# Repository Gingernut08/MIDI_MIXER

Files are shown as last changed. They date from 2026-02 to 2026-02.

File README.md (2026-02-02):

This project lets you use a physical 10-channel MIDI mixer to control the volume of individual apps on Windows. Each fader maps to a specific application, so you can change levels in real time without alt-tabbing or digging through volume sliders.
I built this because I wanted actual knobs and faders for my audio instead of fighting Windows every time Discord got loud.

Full Design



PCB



Wiring diagram



BOM



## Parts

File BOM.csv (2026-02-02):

Item | Number | PPU | Link | Price
Rotary Potentiometer | 2 | 0.695 | https://www.aliexpress.com/item/1005010478158526.html?mp=1 | 1.39
M3 Thread inserts | 10 | 0.334 | https://www.aliexpress.com/item/1005006472962973.html?mp=1 | 3.34
M3 Bolts | 10 | 0.099 | https://www.aliexpress.com/item/1005007197683325.html?mp=1 | 0.99
CA Glue | 1 | 2.09 | https://www.aliexpress.com/item/1005008583356354.html?mp=1 | 2.09
1N4007 Diodes | 28 | 0.093214286 | https://www.aliexpress.com/item/1005009923993443.html?mp=1 | 2.61
Keycaps | 18 | 0.206111111 | https://www.aliexpress.com/item/1005005305167568.html?mp=1 | 3.71
Keyswitches | 18 | 0.288333333 | https://www.aliexpress.com/item/1005006605714880.html?mp=1 | 5.19
TCA9548 | 2 | 0.96 | https://www.aliexpress.com/item/1005006963196608.html?mp=1 | 1.92
3mm Red LED | 10 | 0.068 | https://www.aliexpress.com/item/32873361284.html?mp=1 | 0.68
Slide Potemtiometer | 10 | 0.839 | https://www.aliexpress.com/item/1005007005403318.html?mp=1 | 8.39
0.91" OLED | 10 | 0.95 | https://www.aliexpress.com/item/32798439084.html?mp=1 | 9.5
MCP23017 | 2 | 1.69 | https://www.aliexpress.com/item/1005004670859491.html?mp=1 | 3.38
XIAO RP2040 | 1 | 6.05 | https://www.aliexpress.com/item/1005008484816031.html?mp=1 | 6.05
PCB | 1 | 1.49 | JLC PCB | 1.49
Case Top L | 1 |  | Printed by legion
Case Top R | 1 |  | Printed by legion
Case Bottom L | 1 |  | Printed by legion
Case Bottom M | 1 |  | Printed by legion
Case Bottom R | 1 |  | Printed by legion

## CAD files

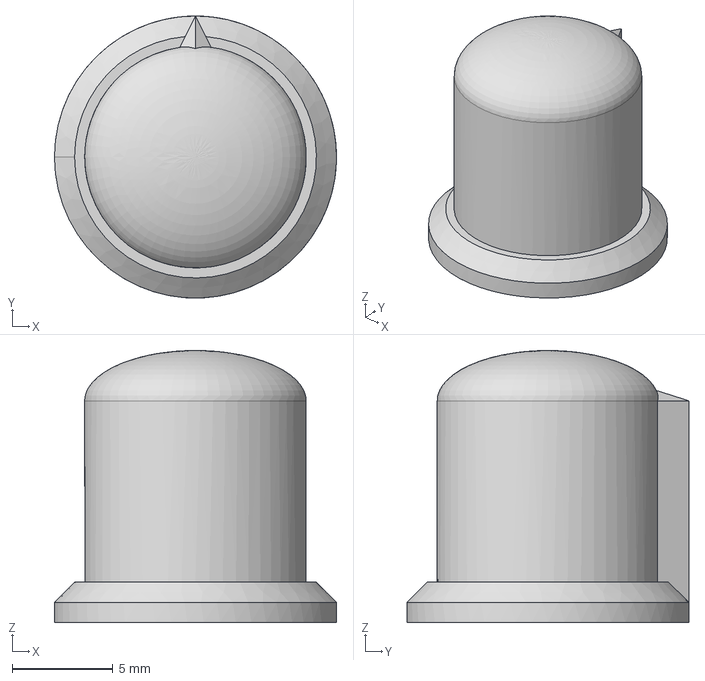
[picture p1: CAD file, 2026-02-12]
CAD/parts/Knob 2.step
14.0 x 14.0 x 13.5 mm

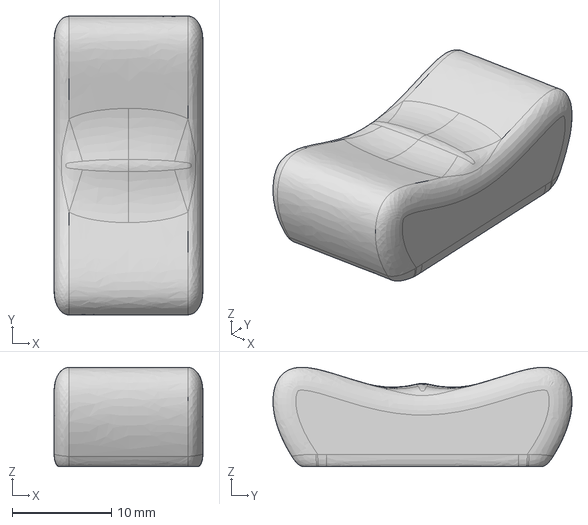
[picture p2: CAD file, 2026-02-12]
CAD/parts/Knob.step
15.0 x 30.1 x 10.0 mm

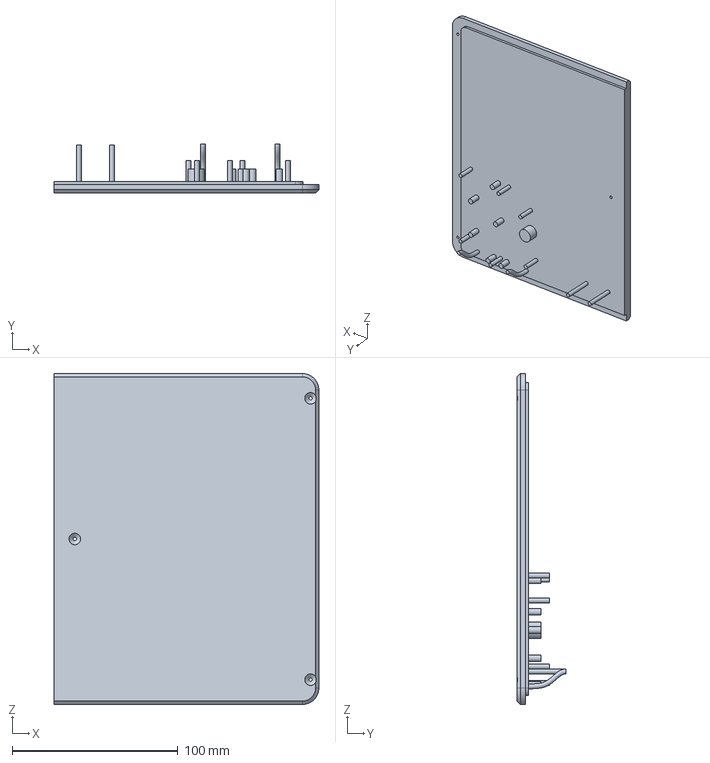
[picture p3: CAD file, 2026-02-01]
CAD/parts/Bottom R.step
160.0 x 29.5 x 200.0 mm

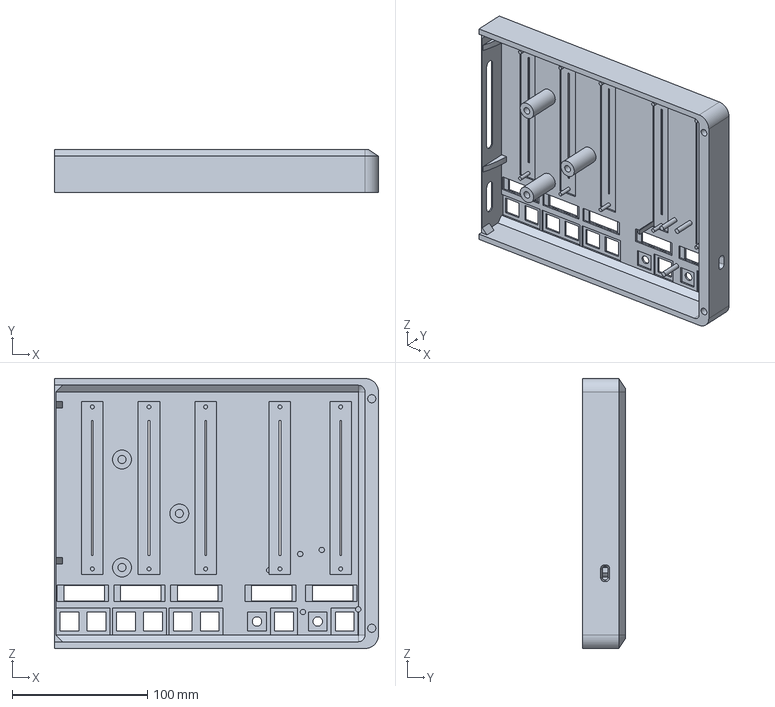
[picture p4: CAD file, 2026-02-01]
CAD/parts/Top R.step
240.0 x 32.0 x 200.0 mm

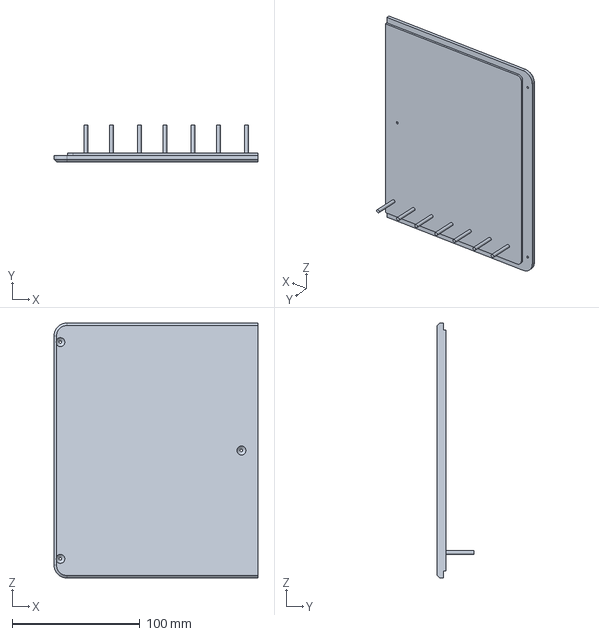
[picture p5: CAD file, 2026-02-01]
CAD/parts/Bottom L.step
160.0 x 29.0 x 200.0 mm

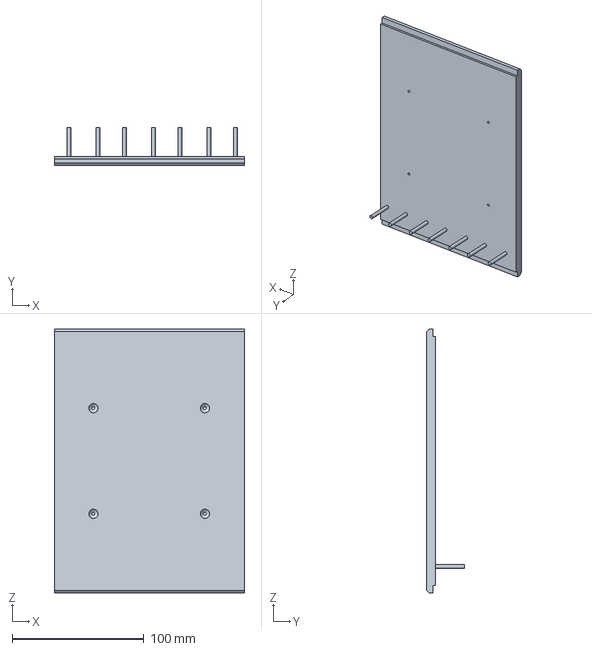
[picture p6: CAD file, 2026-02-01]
CAD/parts/Bottom M.step
144.0 x 29.0 x 200.0 mm

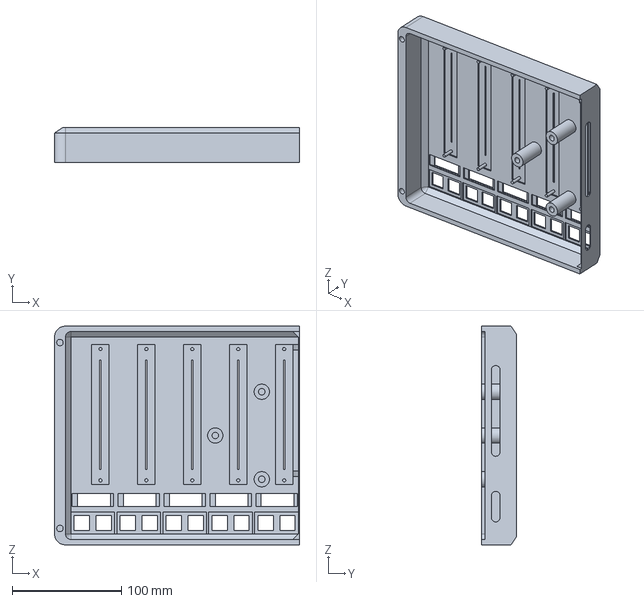
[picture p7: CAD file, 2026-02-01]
CAD/parts/Top L.step
224.0 x 32.0 x 200.0 mm

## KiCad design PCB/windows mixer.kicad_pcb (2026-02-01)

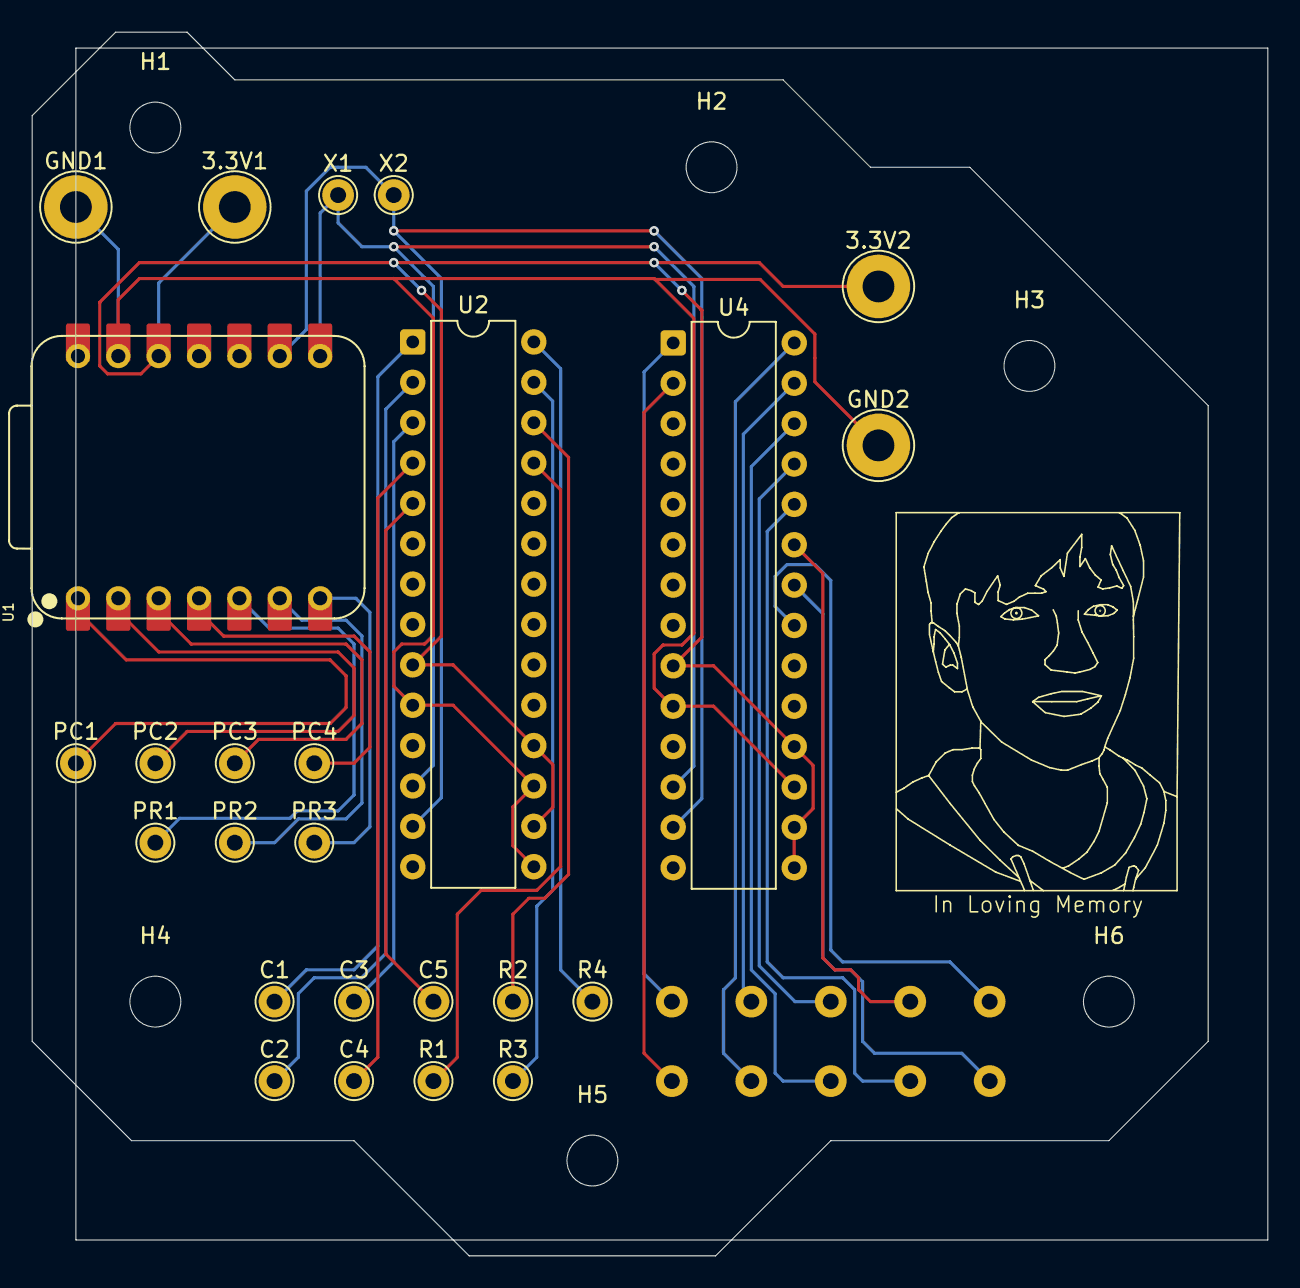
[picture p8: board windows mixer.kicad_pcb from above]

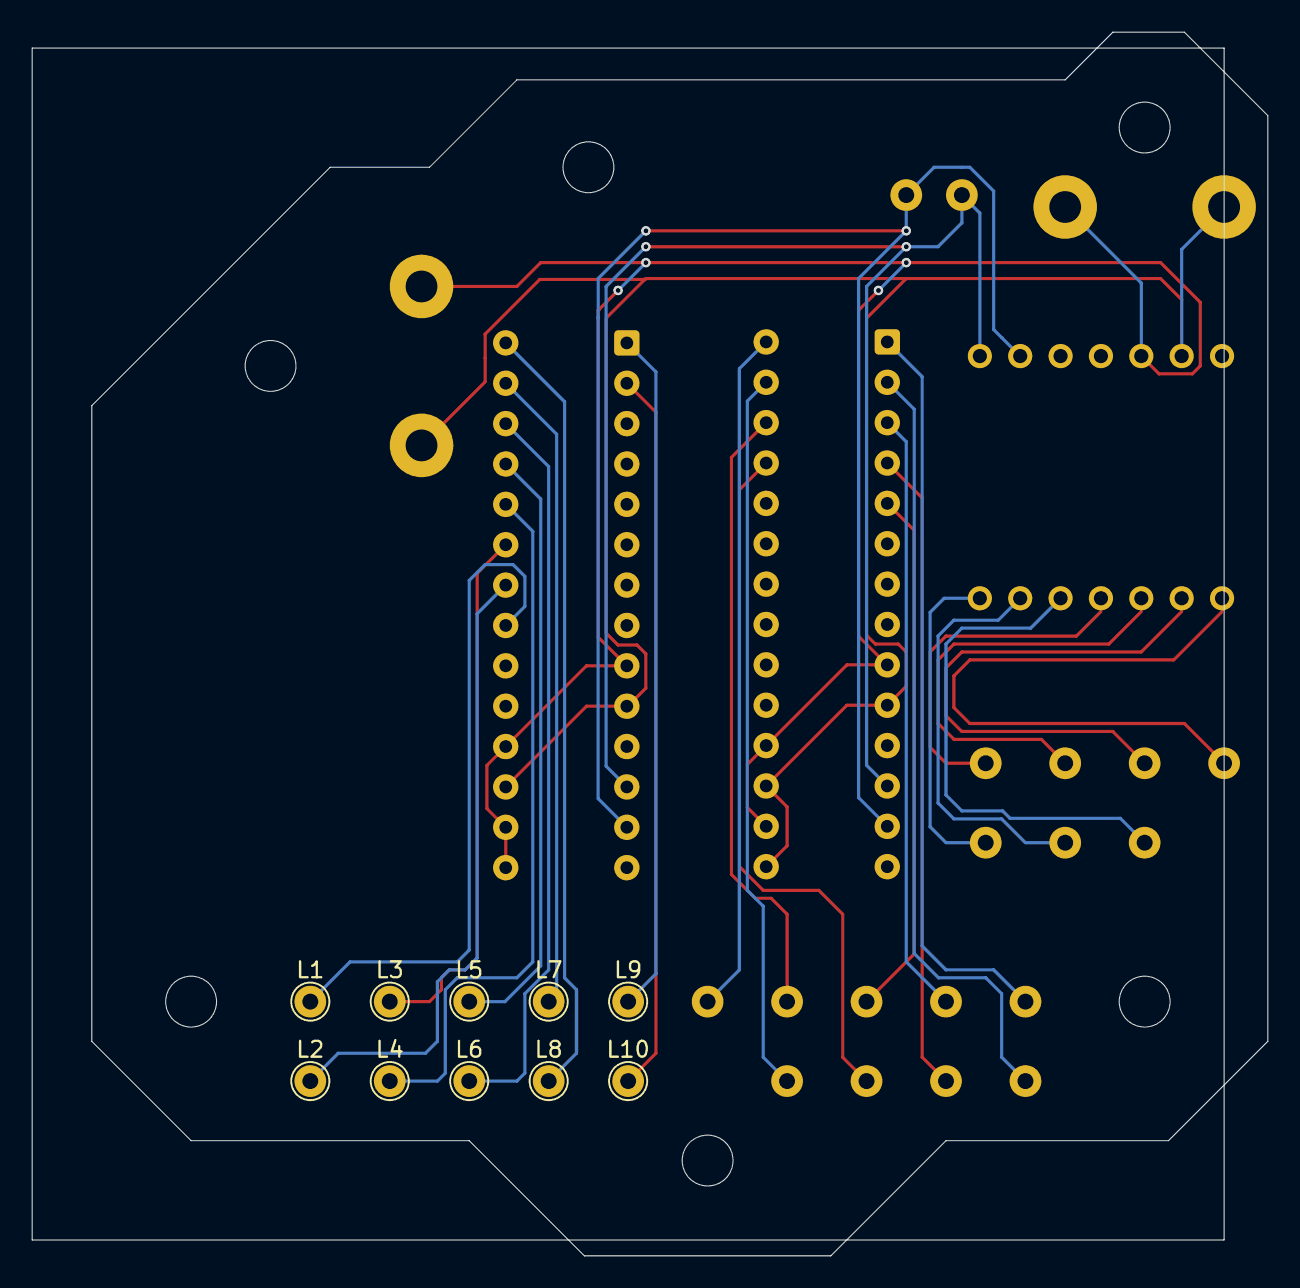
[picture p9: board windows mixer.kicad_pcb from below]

Board: 2 copper layers, 77.8 x 77.0 mm, 41 parts (10 on the bottom side), 30 nets.

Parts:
3.3V1, 3.3V2: TestPoint; TestPoint_THTPad_D4.0mm_Drill2.0mm
C1, C2, C3, C4, C5: TestPoint; TestPoint_THTPad_D2.0mm_Drill1.0mm
GND1, GND2: TestPoint; TestPoint_THTPad_D4.0mm_Drill2.0mm
H1, H2, H3, H4, H5, H6: MountingHole; MountingHole_3.2mm_M3
L1, L2, L3, L4, L5, L6, L7, L8, L9, L10: TestPoint; TestPoint_THTPad_D2.0mm_Drill1.0mm
PC1, PC2, PC3, PC4: TestPoint; TestPoint_THTPad_D2.0mm_Drill1.0mm
PR1, PR2, PR3: TestPoint; TestPoint_THTPad_D2.0mm_Drill1.0mm
R1, R2, R3, R4: TestPoint; TestPoint_THTPad_D2.0mm_Drill1.0mm
U1: XIAO-RP2040-DIP
U2, U4: MCP23017_SP; DIP-28_W7.62mm
X1, X2: TestPoint; TestPoint_THTPad_D2.0mm_Drill1.0mm

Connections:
+3.3V: 3.3V1.1, 3.3V2.1, U1.12 (3V3), U2.9 (VDD), U2.16 (A1), U2.18 (~RESET), U4.9 (VDD), U4.15 (A0), U4.16 (A1), U4.18 (~RESET)
/Expander_SCK: U1.8 (GPIO1/RX), U2.12 (SCK), U4.12 (SCK), X1.1
/Expander_SDA: U1.9 (GPIO2/SCK), U2.13 (SDA), U4.13 (SDA), X2.1
/Pot_Group_One: PR1.1, U1.5 (GPIO6/SDA)
/Pot_Group_Three: PR3.1, U1.7 (GPIO0/TX)
/Pot_Group_Two: PR2.1, U1.6 (GPIO7/SCL)
/Pot_Out_Four: PC4.1, U1.4 (GPIO29/ADC3/A3)
/Pot_Out_One: PC1.1, U1.1 (GPIO26/ADC0/A0)
/Pot_Out_Three: PC3.1, U1.3 (GPIO28/ADC2/A2)
/Pot_Out_Two: PC2.1, U1.2 (GPIO27/ADC1/A1)
GND: GND1.1, GND2.1, U1.13 (GND), U2.10 (VSS), U2.15 (A0), U2.17 (A2), U4.10 (VSS), U4.17 (A2)
unnamed: R1.1, U2.25 (GPA4)
unnamed: R2.1, U2.26 (GPA5)
unnamed: R3.1, U2.27 (GPA6)
unnamed: R4.1, U2.28 (GPA7)
unnamed: L1.1, U4.21 (GPA0)
unnamed: L2.1, U4.22 (GPA1)
unnamed: L3.1, U4.23 (GPA2)
unnamed: L4.1, U4.24 (GPA3)
unnamed: L5.1, U4.25 (GPA4)
unnamed: L6.1, U4.26 (GPA5)
unnamed: L7.1, U4.27 (GPA6)
unnamed: L8.1, U4.28 (GPA7)
unnamed: L9.1, U4.1 (GPB0)
unnamed: L10.1, U4.2 (GPB1)
unnamed: C1.1, U2.1 (GPB0)
unnamed: C2.1, U2.2 (GPB1)
unnamed: C3.1, U2.3 (GPB2)
unnamed: C4.1, U2.4 (GPB3)
unnamed: C5.1, U2.5 (GPB4)

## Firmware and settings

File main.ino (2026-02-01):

#include <MIDI.h>
MIDI_CREATE_DEFAULT_INSTANCE();

/* ---------------- CONFIG ---------------- */

const int NUM_SLIDER_INPUTS  = 4;
const int NUM_SLIDER_OUTPUTS = 3;
const int NUM_SLIDERS        = 10;

const int NUM_ROWS = 5;
const int NUM_COLS = 4;
const int NUM_BUTTONS = NUM_ROWS * NUM_COLS;

/* ----------- PIN DEFINITIONS ------------ */

const int analogInputs[NUM_SLIDER_INPUTS] = {A0, A1, A2, A3};
const int digitalOutputs[NUM_SLIDER_OUTPUTS] = {2, 3, 4};

const int rowPins[NUM_ROWS] = {5, 6, 7, 8, 9};
const int colPins[NUM_COLS] = {10, 11, 12, 13};

/* ------------- STATE ------------------- */

int analogSliderValues[NUM_SLIDERS];
int sliderValues[NUM_SLIDERS];
int lastSliderValues[NUM_SLIDERS];

int buttonValues[NUM_BUTTONS];
int prevButtonValues[NUM_BUTTONS];
int changeButtons[NUM_BUTTONS];

int mutedSlides[NUM_SLIDERS] = {1,1,1,1,1,1,1,1,1,1};

/* -------- APP / CHANNEL HANDLING -------- */

const int NUM_APPS = 10;
int currentApps[NUM_SLIDERS - 2] = {0,1,2,3,4,5,6,7};

/* Buttons that change apps */
const int appChange[NUM_SLIDERS - 2] = {0,2,4,6,8,10,12,14};
/* Buttons that mute sliders */
const int muteChange[NUM_SLIDERS] = {1,3,5,7,9,11,13,15,16,17};

/* ---------------- SETUP ---------------- */

void setup() {
  for (int i = 0; i < NUM_SLIDER_OUTPUTS; i++) {
    pinMode(digitalOutputs[i], OUTPUT);
    digitalWrite(digitalOutputs[i], LOW);
  }

  for (int i = 0; i < NUM_COLS; i++) {
    pinMode(colPins[i], OUTPUT);
    digitalWrite(colPins[i], LOW);
  }

  for (int i = 0; i < NUM_ROWS; i++) {
    pinMode(rowPins[i], INPUT_PULLDOWN);
  }

  MIDI.begin(MIDI_CHANNEL_OMNI);
}

/* ---------------- LOOP ----------------- */

void loop() {
  getSliders();
  getButtons();
  changeMutes();
  changeApps();
  sendMidi();
  delay(5);
}

/* ------------- SLIDERS ----------------- */

void getSliders() {
  for (int out = 0; out < NUM_SLIDER_OUTPUTS; out++) {
    digitalWrite(digitalOutputs[out], HIGH);

    for (int in = 0; in < NUM_SLIDER_INPUTS; in++) {
      int index = out * NUM_SLIDER_INPUTS + in;
      if (index < NUM_SLIDERS) {
        analogSliderValues[index] = analogRead(analogInputs[in]) >> 3; // 0–127
      }
    }

    digitalWrite(digitalOutputs[out], LOW);
  }
}

/* ------------- BUTTON MATRIX ----------- */

void getButtons() {
  for (int c = 0; c < NUM_COLS; c++) {
    digitalWrite(colPins[c], HIGH);

    for (int r = 0; r < NUM_ROWS; r++) {
      int index = c * NUM_ROWS + r;
      buttonValues[index] = digitalRead(rowPins[r]);
    }

    digitalWrite(colPins[c], LOW);
  }

  for (int i = 0; i < NUM_BUTTONS; i++) {
    changeButtons[i] =
      (buttonValues[i] == HIGH && prevButtonValues[i] == LOW);
    prevButtonValues[i] = buttonValues[i];
  }
}

/* ------------- MUTES ------------------- */

void changeMutes() {
  for (int i = 0; i < NUM_SLIDERS; i++) {
    if (changeButtons[muteChange[i]]) {
      mutedSlides[i] = !mutedSlides[i];
    }
  }
}

/* ------------- APPS / CHANNELS -------- */

void changeApps() {
  for (int i = 0; i < NUM_SLIDERS - 2; i++) {
    if (changeButtons[appChange[i]]) {
      currentApps[i]++;
      currentApps[i] %= NUM_APPS;
    }
  }
}

/* ------------- MIDI OUTPUT ------------- */

void sendMidi() {
  for (int i = 0; i < NUM_SLIDERS; i++) {
    int value = mutedSlides[i] ? analogSliderValues[i] : 0;

    if (value != lastSliderValues[i]) {
      int channel = (i < NUM_SLIDERS - 2)
                      ? currentApps[i] + 1
                      : 1;

      MIDI.sendControlChange(i, value, channel);
      lastSliderValues[i] = value;
    }
  }
}
